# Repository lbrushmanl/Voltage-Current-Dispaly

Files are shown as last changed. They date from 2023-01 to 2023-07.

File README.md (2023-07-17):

# Voltage-Current-Dispaly
This project was based around using the 11-digit VFD displays that you can buy for cheap at Jaycar 
https://www.jaycar.co.nz/11-digit-fluoro-display-bargain/p/ZD1880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

As these displays look cool, I came up with the idea of making a voltage current display that I could then use for lots of my other projects. 
The first 5 digits would be voltage and the last 5 for current leaving the centre one blank.

To drive the display, a voltage of around 4.5V is needed for the filament, and 12V is needed for grids and digits. The 4.5V came from an LM317 adjustable voltage regulator.
The board was designed to use an ATMega8, as I had a few from UNI. 

The display was driven via shift registers and a 7seg decoder, as this would only require three GPIO pins on the MCU to be used. It also seemed like a cool idea.

Due to this driver circuitry, the following data structure was formed.

The first 4 bits are the BCD value that the 7seg decoder will read, the 5th bit is the decimal point, and bits 6 to 15 are the grids of the VFD.
A B C D DP G1 G2 G3 G4 G5 G7 G8 G9 G10 G11

I assembled one board fully and found out that a few things were wrong. I also used my ATMegaU4 dev board for testing rather than the ATMega8, as it was easier to use
The main thing I found wrong was the C segment was connected to the comma. I also found out that the Blanking pin of the decoder was connected high rather than low. The biggest issue was that the display was the wrong way around. Flipping it fixed the problem however it no longer looks as good.

View of the test setup


Initial test after fixing the PCB showing 0 and the dot


The first numbers are quite dim


Finaly brighter and the ADC is conected 


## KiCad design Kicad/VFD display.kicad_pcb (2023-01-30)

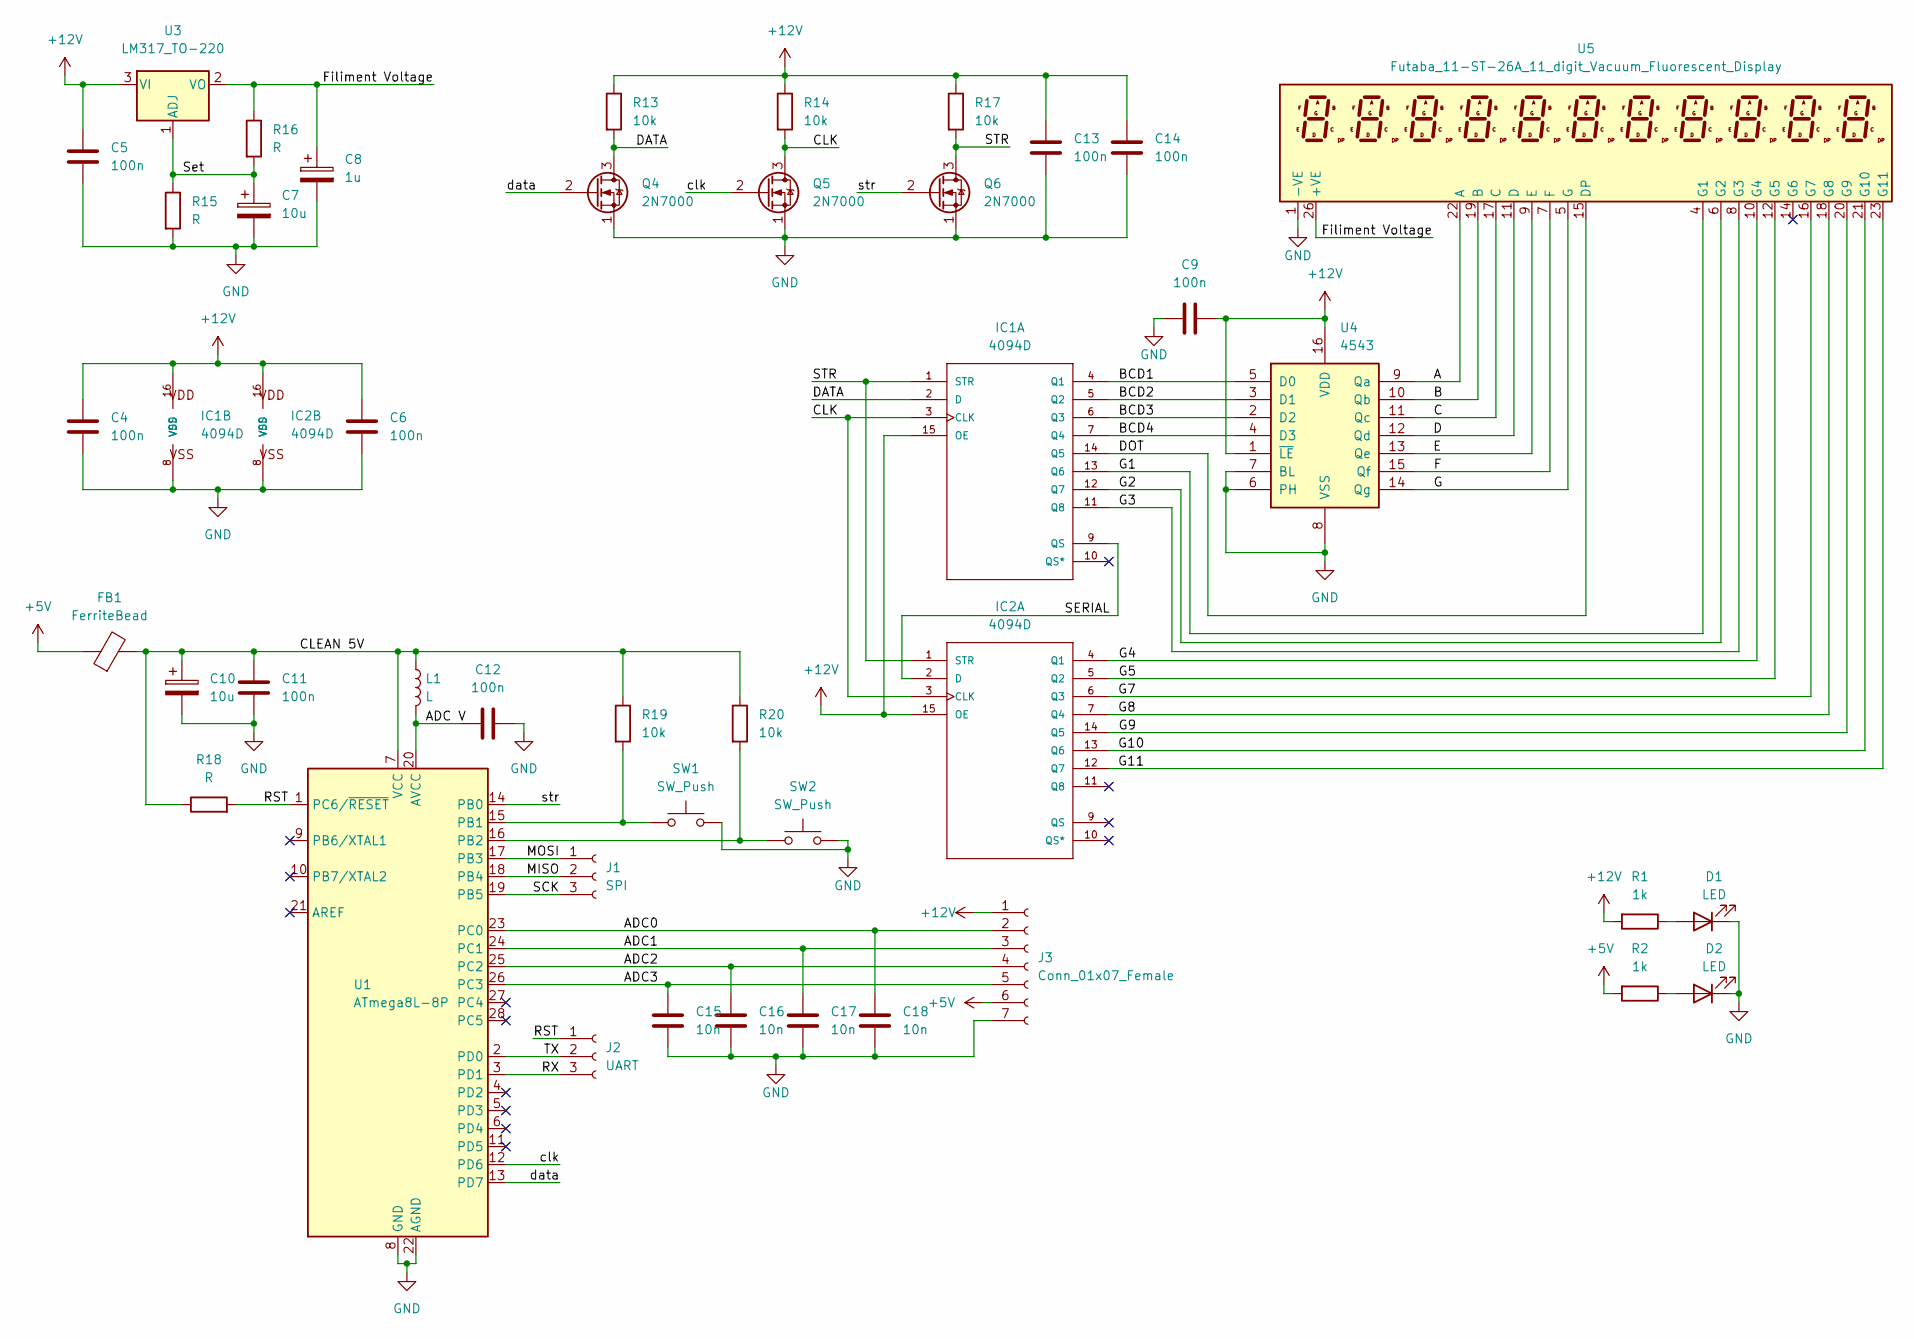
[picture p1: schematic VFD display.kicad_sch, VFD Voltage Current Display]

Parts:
C4, C5, C6, C9, C11, C12, C13, C14: 100n; C_Disc_D3.4mm_W2.1mm_P2.50mm
C7, C10: 10u; CP_Radial_D5.0mm_P2.00mm
C8: 1u; CP_Radial_D5.0mm_P2.00mm
C15, C16, C17: 10n; C_Disc_D4.7mm_W2.5mm_P5.00mm
C18: 10n; C_Disc_D3.4mm_W2.1mm_P2.50mm
D1, D2: LED
FB1: FerriteBead; L_0603_1608Metric_Pad1.05x0.95mm_HandSolder
IC1, IC2: 4094D; DIP-16_W7.62mm_LongPads
J1: SPI; PinSocket_1x03_P2.54mm_Vertical
J2: UART; PinSocket_1x03_P2.54mm_Vertical
J3: Conn_01x07_Female; PinSocket_1x07_P2.54mm_Vertical
L1: L; L_0603_1608Metric_Pad1.05x0.95mm_HandSolder
Q4, Q5, Q6: 2N7000; TO-92_Inline_Wide
R1, R2: 1k
R13, R14, R17, R19, R20: 10k; R_Axial_DIN0207_L6.3mm_D2.5mm_P2.54mm_Vertical
R15, R16, R18: R; R_Axial_DIN0207_L6.3mm_D2.5mm_P2.54mm_Vertical
SW1, SW2: SW_Push; SW_PUSH_6mm
U1: ATmega8L-8P; DIP-28_W7.62mm_LongPads
U3: LM317_TO-220; TO-220-3_Vertical
U4: 4543; DIP-16_W7.62mm_LongPads
U5: Futaba_11-ST-26A_11_digit_Vacuum_Fluorescent_Disp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; PinSocket_1x26_P2.54mm_Vertical

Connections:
+5V: FB1.1, J3.6, R2.2
/Display/A: U4.9 (Qa), U5.22 (A)
/Display/ADC0: C18.1, J3.2, U1.23 (PC0)
/Display/ADC1: C17.1, J3.3, U1.24 (PC1)
/Display/ADC2: C16.1, J3.4, U1.25 (PC2)
/Display/ADC3: C15.1, J3.5, U1.26 (PC3)
/Display/ADC V: C12.1, L1.2, U1.20 (AVCC), U1.21 (AREF)
/Display/B: U4.10 (Qb), U5.19 (B)
/Display/BCD1: IC1.4 (Q1), U4.5 (D0)
/Display/BCD2: IC1.5 (Q2), U4.3 (D1)
/Display/BCD3: IC1.6 (Q3), U4.2 (D2)
/Display/BCD4: IC1.7 (Q4), U4.4 (D3)
/Display/C: U4.11 (Qc), U5.13 (C), U5.17 (C)
/Display/CLEAN 5V: C10.1, C11.1, FB1.2, L1.1, R18.1, R19.1, R20.1, U1.7 (VCC)
/Display/CLK: IC1.3 (CLK), IC2.3 (CLK), Q5.3 (D), R14.2
/Display/D: U4.12 (Qd), U5.11 (D)
/Display/DATA: IC1.2 (D), Q4.3 (D), R13.2
/Display/DOT: IC1.14 (Q5), U5.15 (DP)
/Display/E: U4.13 (Qe), U5.9 (E)
/Display/F: U4.15 (Qf), U5.7 (F)
/Display/Filiment Voltage: C8.1, R16.1, U3.2 (VO), U5.26 (+VE)
/Display/G: U4.14 (Qg), U5.5 (G)
/Display/G1: IC1.13 (Q6), U5.4 (G1)
/Display/G2: IC1.12 (Q7), U5.6 (G2)
/Display/G3: IC1.11 (Q8), U5.8 (G3)
/Display/G4: IC2.4 (Q1), U5.10 (G4)
/Display/G5: IC2.5 (Q2), U5.12 (G5)
/Display/G7: IC2.6 (Q3), U5.16 (G7)
/Display/G8: IC2.7 (Q4), U5.18 (G8)
/Display/G9: IC2.14 (Q5), U5.20 (G9)
/Display/G10: IC2.13 (Q6), U5.21 (G10)
/Display/G11: IC2.12 (Q7), U5.23 (G11)
/Display/MISO: J1.2, U1.18 (PB4)
/Display/MOSI: J1.1, U1.17 (PB3)
/Display/RST: J2.1, R18.2, U1.1 (PC6/~RESET)
/Display/RX: J2.3, U1.3 (PD1)
/Display/SCK: J1.3, U1.19 (PB5)
/Display/SERIAL: IC1.9 (QS), IC2.2 (D)
/Display/STR: IC1.1 (STR), IC2.1 (STR), Q6.3 (D), R17.2
/Display/Set: C7.1, R15.1, R16.2, U3.1 (ADJ)
/Display/TX: J2.2, U1.2 (PD0)
/Display/clk: Q5.2 (G), U1.12 (PD6)
/Display/data: Q4.2 (G), U1.13 (PD7)
/Display/str: Q6.2 (G), U1.14 (PB0)
unnamed: D1.2 (A), R1.1
unnamed: D2.2 (A), R2.1
unnamed: R19.2, SW1.1, U1.15 (PB1)
unnamed: R20.2, SW2.1, U1.16 (PB2)

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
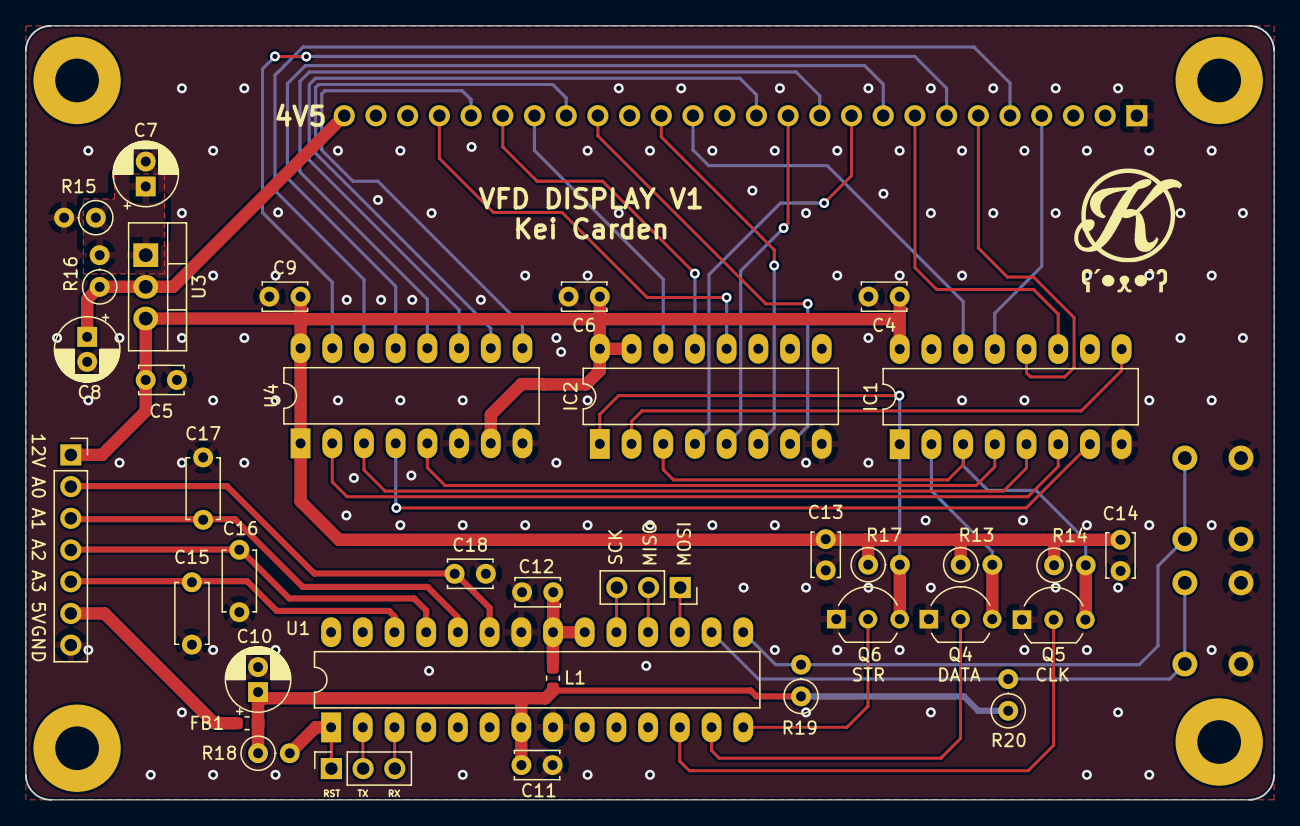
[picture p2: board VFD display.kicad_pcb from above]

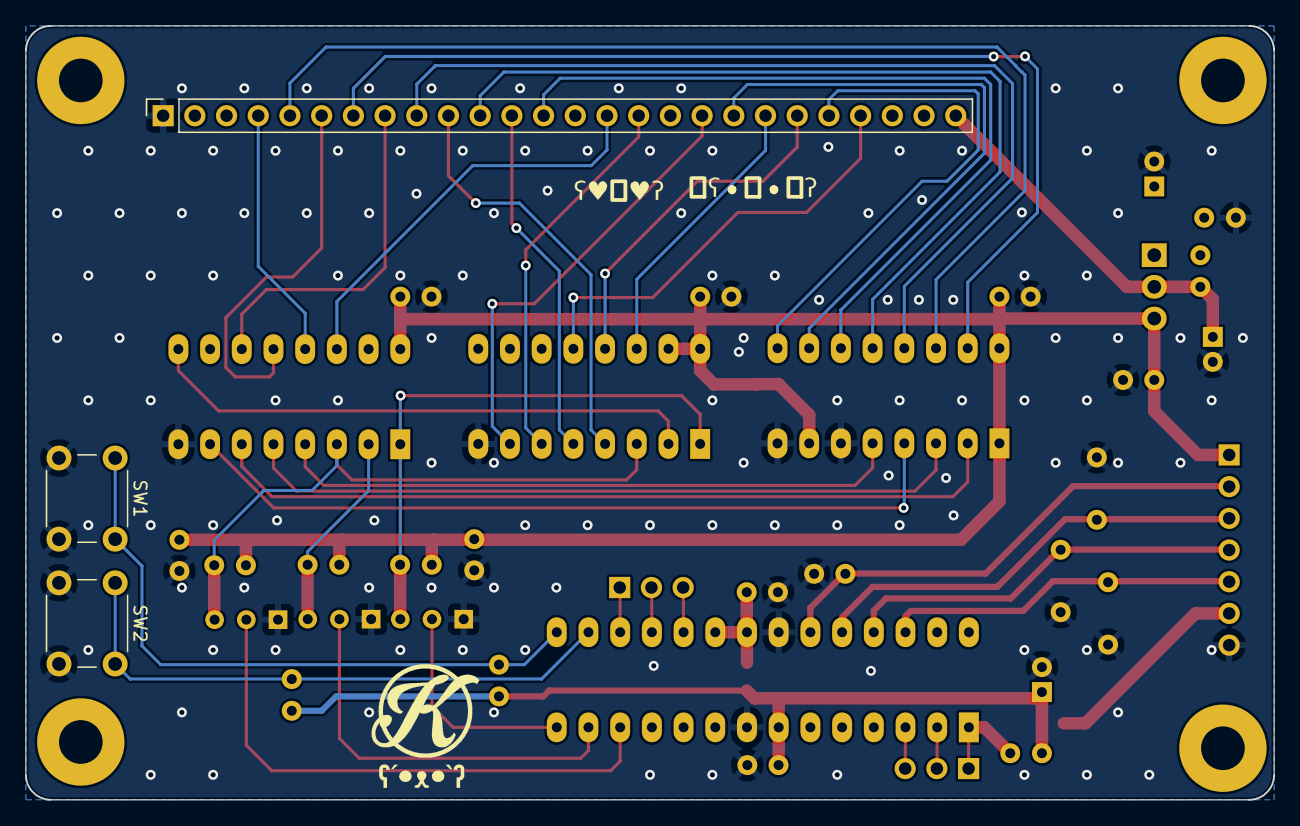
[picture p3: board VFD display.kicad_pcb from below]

Board: 2 copper layers, 100.0 x 62.0 mm, 39 parts (3 on the bottom side), 48 nets.

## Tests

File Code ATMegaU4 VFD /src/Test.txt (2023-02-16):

#include <stdio.h>
#include <stdint.h>

#define VOLTAGE A5
#define CURRENT A4

#define DATA 4
#define CLK 12
#define STR 6

#define GRID_NUMBER 11
#define CONVERSION_FACTOR_30V 29.3255131965 // 30/1023 * 1000
#define CONVERSION_FACTOR_6A 5.8651026393 // 6/1023 * 1000

void display(uint16_t, uint16_t);

int main() 
{
        uint16_t voltage = 5;//analogRead(VOLTAGE) * CONVERSION_FACTOR_30V;
        uint16_t current = 12345;//analogRead(CURRENT) * CONVERSION_FACTOR_6A;
        display(voltage, current);
}

//  BCD
// A B C D DP G1 G2 G3 G4 G5 G7 G8 G9 G10 G11
// 0 0 0 1 0 0 1 1 1 1 1 1 1 1 1 0 0 

void display(uint16_t voltage, uint16_t current) 
{

  uint32_t bin = (voltage * 100000) + current;

  for (uint8_t grid_index = 0; grid_index < GRID_NUMBER; grid_index++)
  {
    uint16_t display_value = 0;
    // Extracts each value from a number
    display_value = (bin % 10);
    bin /= 10;
    printf("%d\n", display_value);

    // // Ensures that only spacific grids can be energises
    if (grid_index == 6)
    {
      grid_index = 7;
    } else if (grid_index == 4 || grid_index == 10) 
    {
      display_value += 1 << 4;
    }
    
    // Moves to the next grid
    display_value += 1 << (15 - grid_index);

    printf("\n");
    // Shifts the value in to the shift register
    for (uint8_t i = 0; i < 16; i++)  {
        printf("%d", (display_value & 32768) == 0);
        display_value <<= 1;
        //printf("CLK 0\n");
		//printf("CLK 1\n");
    }		
    printf("\n");
  }
}

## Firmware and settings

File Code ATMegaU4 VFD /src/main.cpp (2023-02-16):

#include <Arduino.h>

#define VOLTAGE A5
#define CURRENT A4

#define DATA 4
#define CLK 12
#define STR 6

#define GRID_NUMBER 11
#define VOLTAGE_CONVERSION_FACTOR 29.3255131965 // 30/1023 * 1000
#define CURRENT_CONVERSION_FACTOR 4.88758553 //5.8651026393 // 6/1023 * 1000

void display(uint16_t, uint16_t);

uint16_t voltage = 12345;
uint16_t current = 34577;

void setup() {
  Serial.begin(9600);
  pinMode(DATA, OUTPUT);
  pinMode(CLK, OUTPUT);
  pinMode(STR, OUTPUT);

  digitalWrite(STR, HIGH);
  digitalWrite(DATA, HIGH);
  digitalWrite(CLK, HIGH);

//Set up interrupt
cli();
TCCR1A = 0;
TCCR1B = 0;
TCNT1 = 0;

OCR1A = 1000;
TCCR1A |= (1 << WGM11);
TCCR1B |= (1 << CS12) | (1 << CS10);  
TIMSK1 |= (1 << OCIE1A);

sei();
}

ISR(TIMER1_COMPA_vect) 
{
  float vc = analogRead(VOLTAGE) * VOLTAGE_CONVERSION_FACTOR;
  float cc = analogRead(CURRENT) * CURRENT_CONVERSION_FACTOR;
  voltage = vc;
  current = cc;
}

void loop() {  
  display(voltage, current);
}

// Data Setup
// BCD		Grids
// A B C D DP G1 G2 G3 G4 G5 G7 G8 G9 G10 G11
// 0 0 0 1 0 0 1 1 1 1 1 1 1 1 1 0 0 


//As the level shifter I made is shit and acts as an inverter the code is inverted to how u would normal put data in to shift registers. Next time ill use the bidirectional level shifter
void display(uint16_t voltage, uint16_t current) 
{

  uint32_t bin = (voltage * 100000) + current;
  

  for (uint8_t grid_index = 0; grid_index < GRID_NUMBER; grid_index++)
  {
    uint16_t display_value = 0;
    // Extracts each value from a number
    display_value = (bin % 10);
    bin /= 10;

    // // Ensures that only spacific grids can be energises
    if (grid_index == 6)
    {
      grid_index = 7;
    } else if (grid_index == 4 || grid_index == 9) 
    {
      display_value += 1 << 4;
    }
    
    // Moves to the next grid
    display_value += 1 << (15 - grid_index);

    digitalWrite(STR, HIGH);
    for (uint8_t i = 0; i < 16; i++)  {
        digitalWrite(DATA, (display_value & 32768) == 0);
        display_value <<= 1;
        digitalWrite(CLK, LOW);
		    digitalWrite(CLK, HIGH);
    }		
    digitalWrite(STR, LOW);
    digitalWrite(STR, HIGH);
  }
}

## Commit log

2023-01-30 Og VFD project
    [VFD display.kicad_pcb, VFD display.kicad_sch]
2023-01-30 V2 Schematic updates added indication LEDs for 12V and 5V, fixed the display symbol so C is connected to pin 17, added values to the capacitors on the ADC lines, removed voltage from AREF.
    [VFD display.kicad_pcb, VFD display.kicad_sch]
2023-02-16 Added VFD test code
    [VFD display.kicad_pcb, VFD display.kicad_sch]
